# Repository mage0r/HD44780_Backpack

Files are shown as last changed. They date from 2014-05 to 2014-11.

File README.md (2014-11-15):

Attiny 84 LCD Display for the HD44780
=============

This project uses an Attiny 84 to drive LCD Displays that use the HD44780 driver.  It's simple, small and compatible with a range of sizes.  The board can easily be trimmed down to the standard 16x2 size or left at it's original size for 20x4.

This version includes a large prototyping area and a mounting for a "mesthingy" from http://www.m9design.co/

There are three sections, the circuit design for kicad, some i2c arduino sketches and a few photos of the finished product.

This version is compatible with Marc Merlin's NewLiquidCrystal library (https://github.com/marcmerlin)

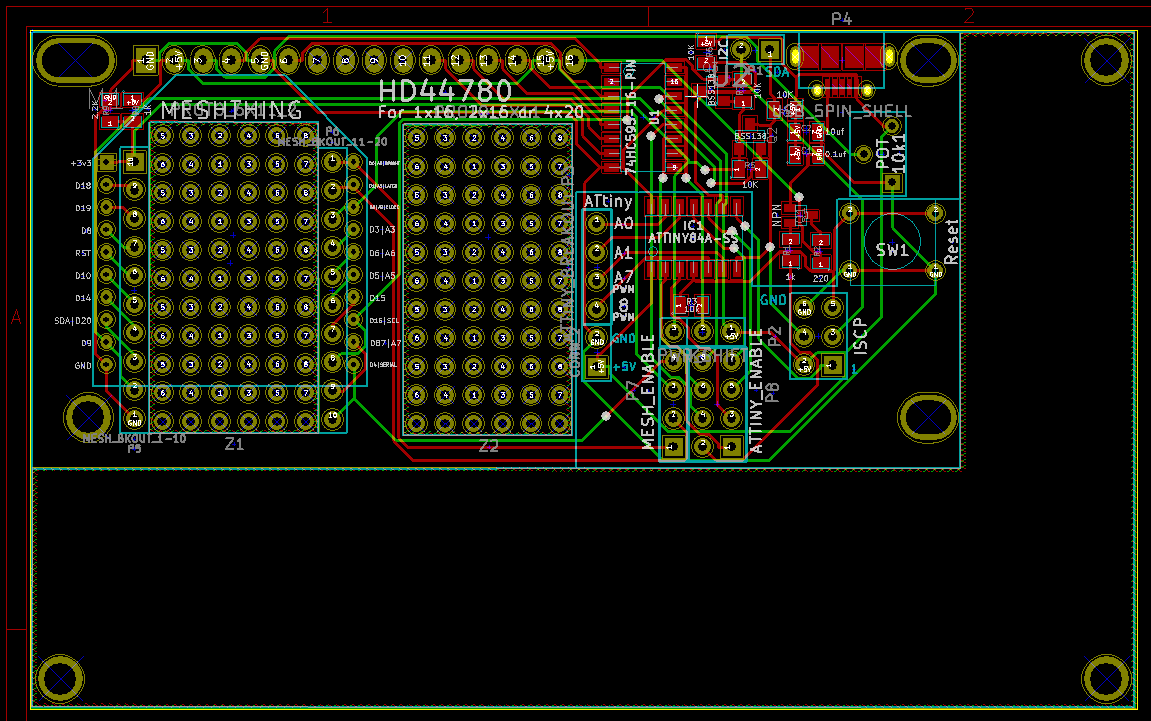
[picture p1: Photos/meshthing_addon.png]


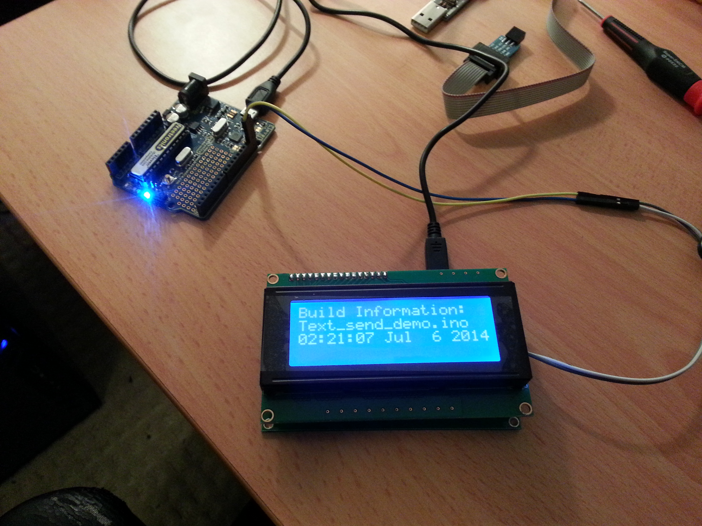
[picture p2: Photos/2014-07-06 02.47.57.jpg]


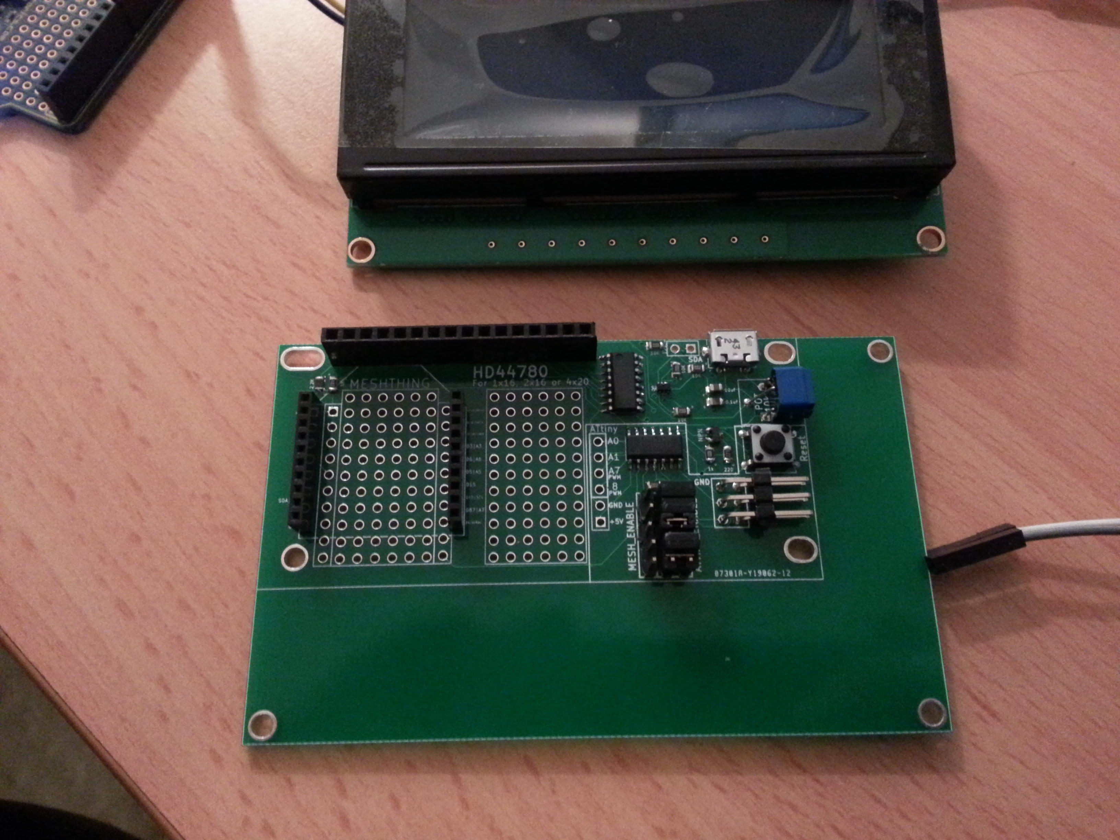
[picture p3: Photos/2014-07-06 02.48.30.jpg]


CREDITS
------------
This project was designed by John Spencer - john.spencer.9000@gmail.com - https://github.com/mage0r

SPECIAL THANKS
------------

To the HackMelbourne (CCHS, http://hackmelbourne.org) community of Melbourne, Australia.

To all other open-source developers whose countless hours supported every other aspect of this design.

DISTRIBUTION
------------
The specific terms of distribution of this project are governed by the
license referenced below. Please contact the copyright owner if you wish to modify the board for distribution. Please utilize this design for personal or research projects. Please acknowledge all contributors.

LICENSE
-------
Licensed under the TAPR Open Hardware License (www.tapr.org/OHL).
The "license" sub-folder also contains a copy of this license in plain text format.

Copyright John Spencer 2014
john.spencer.9000@gmail.com

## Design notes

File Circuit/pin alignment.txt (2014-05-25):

//   +--------------------------------------------+
//   |    attiny 84 		                  |
//   |    D03           D02           D09         |
//   +----+-------------+-------------+-----------+
//        |4            |5            |6
//        |1            |2            |3
//   +----+-------------+-------------+-----------+
//   |    Strobe        Data          Clock       |
//   |    74HC595 8-bit shift/latch register      |
//   |    QH   QG   QF   QE   QD   QC   QB   QA   |
//   +----+----+----+----+----+----+----+----+----+
//        |7   |6   |5   |4   |3   |2   |1   |15
//        |    |14  |13  |12  |11  |4   | 
//   +----+----+----+----+----+----+----+---------+
//   |         DB7  DB6  DB5  DB4  RS             |
//   |               LCD KS0066                   |
//   +--------------------------------------------

//   +----+-------------+-------------+-----------+
//   |    Strobe        Data          Clock       |
//   |          8-bit shift/latch register        | 74HC595N
//   |    Qa0  Qb1  Qc2  Qd3  Qe4  Qf5  Qg6  Qh7  |
//   +----+----+----+----+----+----+----+----+----+
//        |    |    |    |    |    |    |    
//        |11  |12  |13  |14  |6   |5   |4   (LCD pins)
//   +----+----+----+----+----+----+----+----+----+
//   |    DB4  DB5  DB6  DB7  E    Rw   RS        |
//   |                 LCD Module                 |
//
// NOTE: Rw is not used by the driver so it can be connected to GND

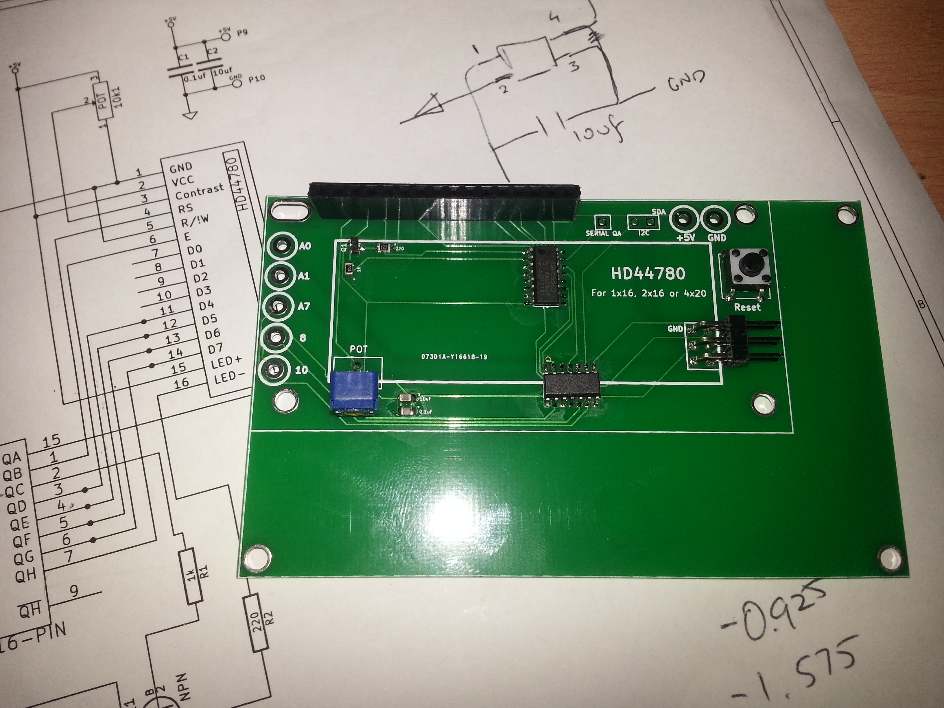
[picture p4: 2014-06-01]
Photos/2014-06-01 22.12.19.jpg

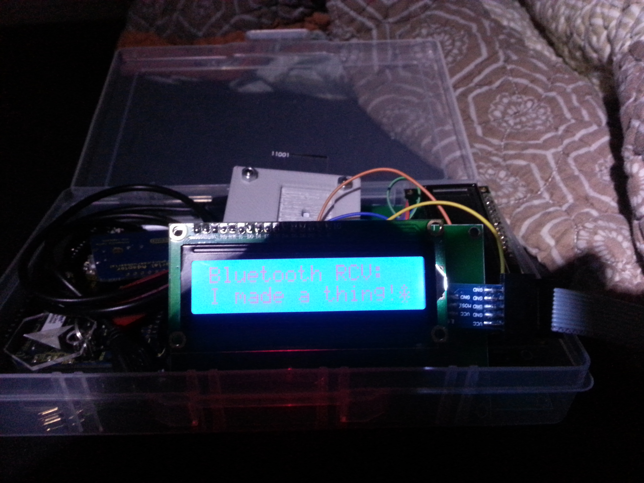
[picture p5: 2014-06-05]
Photos/2014-06-06 01.45.17.jpg

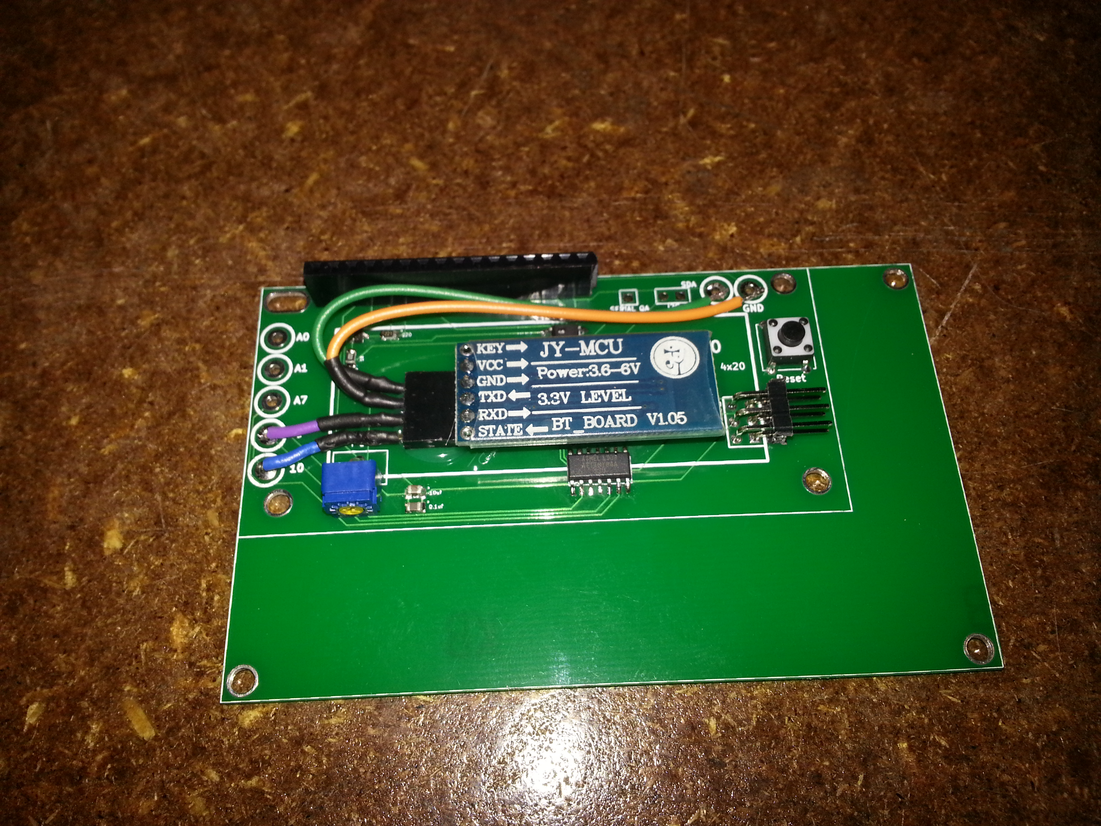
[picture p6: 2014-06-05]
Photos/2014-06-06 00.19.26.jpg

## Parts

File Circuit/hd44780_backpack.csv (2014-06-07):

ref | value | datasheet | footprint | Field1 | Field2 | Field3 | Field4 | Field5 | Field6 | Field7 | Field8
10k1 | POT | http://copal-electronics.info/en/00011/0064d.pdf | ~ | http://copal-electronics.info/en/00011/0064d.pdf | 0.77 | http://www.digikey.com.au/product-search/en?vendor=0&keywords=CT6EP103-ND
C1 | 0.1uf | ~ | ~ | ~
C2 | 10uf | ~ | ~ | ~
IC1 | ATTINY84A-SS | http://www.atmel.com/Images/doc8006.pdf | SO14 | http://www.atmel.com/Images/doc8006.pdf | 0.87
P1 | I2C | ~ | ~ | ~
P2 | ISCP | ~ | ~ | ~
P3 | A0
P4 | A1
P5 | A7
P6 | 8
P7 | 10
P8 | SERIAL QA
P9 | +5V
P10 | GND
Q1 | NPN | ~ | ~ | ~
R1 | 1k | ~ | ~ | ~
R2 | 220 | ~ | ~ | ~
SW1 | Reset | http://www.te.com/commerce/DocumentDelivery/DDEController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 | ~ | http://www.te.com/commerce/DocumentDelivery/DDEController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 | 0.1 | http://www.digikey.com.au/product-detail/en/FSM4JH/450-1650-ND/1632536
U1 | 74HC595-16-PIN | http://www.nxp.com/documents/data_sheet/74HC_HCT595.pdf | so-16 | http://www.nxp.com/documents/data_sheet/74HC_HCT595.pdf | 0.04
U2 | HD44780

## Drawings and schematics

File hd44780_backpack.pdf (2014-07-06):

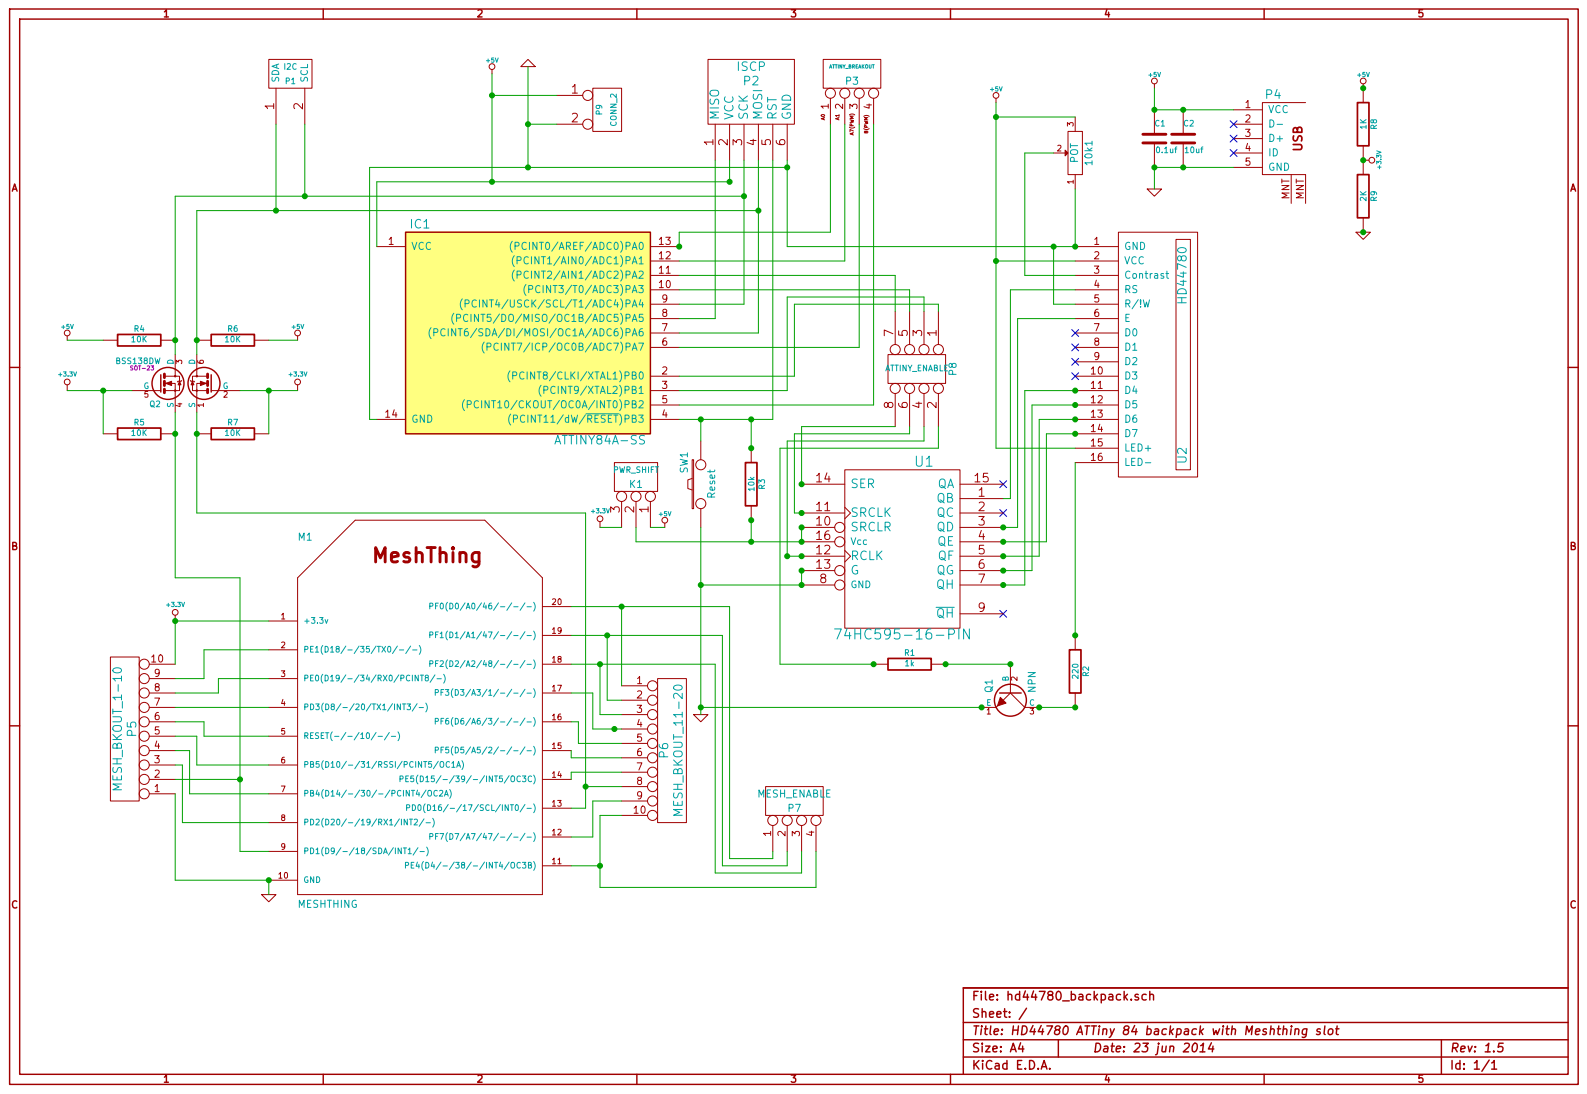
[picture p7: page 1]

File: hd44780_backpack.sch
Sheet: /
Title: HD44780 ATTiny 84 backpack with Meshthing slot
KiCad E.D.A.

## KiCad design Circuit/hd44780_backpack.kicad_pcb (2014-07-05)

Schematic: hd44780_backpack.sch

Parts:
10k1: POT
C1: 0.1uf
C2: 10uf
IC1: ATTINY84A-SS; SO14
K1: PWR_SHIFT
M1: MESHTHING; MeshThing
P1: I2C
P2: ISCP
P3: ATTINY_BREAKOUT
P4: USB_5PIN_SHELL
P5: MESH_BKOUT_1-10
P6: MESH_BKOUT_11-20
P7: MESH_ENABLE
P8: ATTINY_ENABLE
P9: CONN_2
Q1: NPN
Q2: BSS138DW; SOT-23
R1: 1k
R2: 220
R3: 10k
R4, R5, R6, R7: 10K
R8: 1K
R9: 2K
SW1: Reset
U1: 74HC595-16-PIN
U2: HD44780

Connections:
+3.3V: K1.3, M1.1 (+3.3v), P5.10, Q2.2 (G), Q2.5 (G), R5.1, R7.2, R8.2, R9.1
+5V: 10k1.3, C1.1, C2.1, IC1.1 (VCC), K1.1, P2.2 (VCC), P4.1 (VCC), P9.1, R4.1, R6.2, R8.1, U2.2 (VCC), U2.15 (LED+)
GND: 10k1.1, C1.2, C2.2, IC1.14 (GND), M1.10 (GND), P2.6 (GND), P4.5 (GND), P5.1, P9.2 (PM), Q1.1 (E), R9.2, SW1.1, U1.8, U1.13, U2.1 (GND), U2.5 (R/!W)
unnamed: U1.4, U2.14 (D7)
unnamed: IC1.11 ((PCINT2/AIN1/ADC2)PA2), P8.7
unnamed: R2.1, U2.16 (LED-)
unnamed: P8.2, R1.1
unnamed: Q1.3 (C), R2.2
unnamed: Q1.2 (B), R1.2
unnamed: U1.3, U2.6 (E)
unnamed: U1.1, U2.4 (RS)
unnamed: U1.5, U2.13 (D6)
unnamed: U1.6, U2.12 (D5)
unnamed: U1.7, U2.11 (D4)
unnamed: M1.15 (PF5(D5/A5/2/-/-/-)), P6.6
unnamed: M1.14 (PE5(D15/-/39/-/INT5/OC3C)), P6.7
unnamed: M1.11 (PE4(D4/-/38/-/INT4/OC3B)), P6.10, P7.4
unnamed: M1.12 (PF7(D7/A7/47/-/-/-)), P6.9
unnamed: P8.4, U1.12
unnamed: IC1.5 ((PCINT10/CKOUT/OC0A/INT0)PB2), P3.4 (8)
unnamed: IC1.6 ((PCINT7/ICP/OC0B/ADC7)PA7), P3.3 (A7)
unnamed: IC1.12 ((PCINT1/AIN0/ADC1)PA1), P3.2 (A1)
unnamed: IC1.8 ((PCINT5/DO/MISO/OC1B/ADC5)PA5), P2.1 (MISO)
unnamed: K1.2 (PM), R3.2, U1.10, U1.16
unnamed: IC1.13 ((PCINT0/AREF/ADC0)PA0), P3.1 (A0)
unnamed: IC1.4 ((PCINT11/dW/~RESET~)PB3), P2.5 (RST), R3.1, SW1.2
unnamed: 10k1.2, U2.3 (Contrast)
unnamed: P8.6, U1.11
unnamed: P8.8, U1.14
unnamed: IC1.2 ((PCINT8/CLKI/XTAL1)PB0), P8.1
unnamed: IC1.3 ((PCINT9/XTAL2)PB1), P8.3
unnamed: IC1.10 ((PCINT3/T0/ADC3)PA3), P8.5
unnamed: M1.19 (PF1(D1/A1/47/-/-/-)), P6.2, P7.2
unnamed: M1.20 (PF0(D0/A0/46/-/-/-)), P6.1, P7.1
unnamed: M1.18 (PF2(D2/A2/48/-/-/-)), P6.3, P7.3
unnamed: M1.16 (PF6(D6/A6/3/-/-/-)), P6.5
unnamed: M1.5 (RESET(-/-/10/-/-)), P5.6
unnamed: M1.17 (PF3(D3/A3/1/-/-/-)), P6.4
unnamed: M1.2 (PE1(D18/-/35/TX0/-/-)), P5.9
unnamed: M1.3 (PE0(D19/-/34/RX0/PCINT8/-)), P5.8
unnamed: M1.4 (PD3(D8/-/20/TX1/INT3/-)), P5.7
unnamed: M1.6 (PB5(D10/-/31/RSSI/PCINT5/OC1A)), P5.5
unnamed: M1.7 (PB4(D14/-/30/-/PCINT4/OC2A)), P5.4
unnamed: M1.8 (PD2(D20/-/19/RX1/INT2/-)), P5.3
unnamed: IC1.7 ((PCINT6/SDA/DI/MOSI/OC1A/ADC6)PA6), P1.1 (SDA), P2.4 (MOSI), Q2.6 (D), R6.1
unnamed: M1.13 (PD0(D16/-/17/SCL/INT0/-)), P6.8, Q2.1 (S), R7.1
unnamed: IC1.9 ((PCINT4/USCK/SCL/T1/ADC4)PA4), P1.2 (SCL), P2.3 (SCK), Q2.3 (D), R4.2
unnamed: M1.9 (PD1(D9/-/18/SDA/INT1/-)), P5.2, Q2.4 (S), R5.2

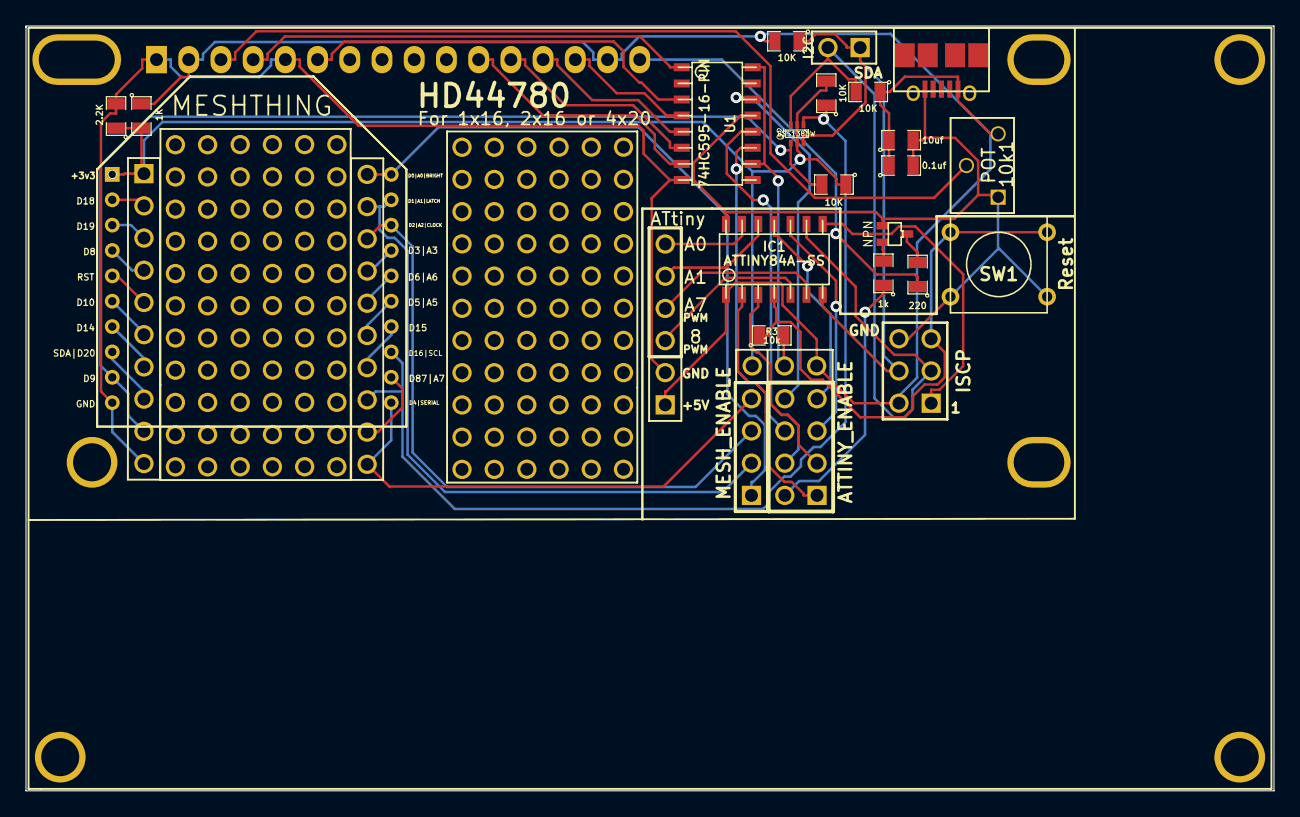
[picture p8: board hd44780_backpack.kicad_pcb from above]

Board: 2 copper layers, 98.4 x 60.3 mm, 31 parts (0 on the bottom side), 48 nets.

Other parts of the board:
PROTO_6X11: Z2; PROTO_6x11
PROTO_6X11_2: Z1; PROTO_6x11

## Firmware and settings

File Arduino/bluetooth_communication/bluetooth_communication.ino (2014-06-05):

/* This project combines the code from a few different sources.
This project was put together by ScottC on the 15/01/2013
http://arduinobasics.blogspot.com/

Bluetooth slave code by Steve Chang - downloaded from :
http://www.seeedstudio.com/wiki/index.php?title=Bluetooth_Shield

Changed for use on attiny 84 + Shift Register driven LCD panel by John Spencer, 2014

*/
 
#include <SoftwareSerial.h> //Software Serial Port
//#include <Wire.h>
#include <LiquidCrystal_SR_LCD3.h>

const int PIN_LCD_STROBE         =  9;  // Out: LCD IC4094 shift-register strobe
const int PIN_LCD_DATA           =  2;  // Out: LCD IC4094 shift-register data
const int PIN_LCD_CLOCK          =  3;  // Out: LCD IC4094 shift-register clock
const int PIN_LCD_BACKLIGHT      =  5;  // Out: LCD backlight (PWM)

// srdata / srclock / strobe
LiquidCrystal_SR_LCD3 lcd(PIN_LCD_DATA, PIN_LCD_CLOCK, PIN_LCD_STROBE);

#define RxD 8 // This is the pin that the Bluetooth (BT_TX) will transmit to the Arduino (RxD)
#define TxD 10 // This is the pin that the Bluetooth (BT_RX) will receive from the Arduino (TxD)
 
#define DEBUG_ENABLED 1

SoftwareSerial blueToothSerial(RxD,TxD);

String btName = "leostick";
String btPin = "1234";

String command = "";

/*----------------------SETUP----------------------------*/ 
void setup() { 
 //Serial.begin(9600); // Allow Serial communication via USB cable to computer (if required)
 
 pinMode(RxD, INPUT); // Setup the Arduino to receive INPUT from the bluetooth shield on Digital Pin 6
 pinMode(TxD, OUTPUT); // Setup the Arduino to send data (OUTPUT) to the bluetooth shield on Digital Pin 7
 
  
  lcd.begin(16, 2);
  
  //Serial.println("Waiting...");
  lcd.setCursor(0,0);
  lcd.print("I use Bluetooth...");
  lcd.setCursor(0,1);
  lcd.print("Connect to ");
  lcd.print(btName);
  
  setupBlueToothConnection(); //Used to initialise the Bluetooth shield

} 

/*----------------------LOOP----------------------------*/ 
void loop() { 
 char recvChar;

  if (blueToothSerial.available()) {
    while(blueToothSerial.available()) { // While there is more to be read, keep reading.
	command += (char)blueToothSerial.read();
    }
    //Serial.println(command);
    
    lcd.clear();
    lcd.setCursor(0,0);
    lcd.print("Bluetooth RCV:");
    
    lcd.setCursor(0,1);
    lcd.print(command);
    
    
     
    
    command = ""; // No repeats
  }
 
 /*
 //You can use the following code to deal with any information coming from the Computer (serial monitor)
 if(Serial.available()){
   recvChar = Serial.read();
   //This will send value obtained (recvChar) to the phone. The value will be displayed on the phone.
   blueToothSerial.print(recvChar);
   }
 */
} 



//The following code is necessary to setup the bluetooth shield ------copy and paste----------------
void setupBlueToothConnection()
{
 blueToothSerial.begin(9600); //Set BluetoothBee BaudRate to default baud rate 38400
 //blueToothSerial.print("\r\n+STWMOD=0\r\n"); //set the bluetooth work in slave mode
 //Serial.println("Sending name command to bluetooth\r\nAT+NAME = "+btName+"\r\n");
 //Serial.println(blueToothSerial.print("\r\nAT+NAME="+btName+"\r\n")); //set the bluetooth name
 //blueToothSerial.print("\r\n+STOAUT=1\r\n"); // Permit Paired device to connect me
 //blueToothSerial.print("\r\n+STAUTO=0\r\n"); // Auto-connection should be forbidden here
 delay(2000); // This delay is required.
 //blueToothSerial.print("\r\n+INQ=1\r\n"); //make the slave bluetooth inquirable 
 //Serial.println("The slave bluetooth is inquirable!");
 delay(2000); // This delay is required.
 blueToothSerial.flush();
}

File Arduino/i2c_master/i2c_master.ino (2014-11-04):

/*

  Control menu for I2C HD44780 backpacks.
  John Spencer - 2014
  https://github.com/mage0r/HD44780_Backpack
  
  Adapted from:
  http://www.forkrobotics.com/2012/05/relay-control-over-i2c/
  
  
  
*/

#include <Wire.h>
byte ATtinyAddress; // this is the address we are sending to.  Set in setup()

String inputString = "";         // a string to hold incoming data
boolean stringComplete = false;  // whether the string is complete

String receiveString = "";

int toReceive = 0;

void setup(){
    Wire.begin();
    Serial.begin(9600);
    
    inputString.reserve(200);
    findDevices(); // who is on this bus?
    PrintMenu();
    Serial.print("Writing to device: ");
    Serial.println(ATtinyAddress);
    
}
void loop(){
  
  // check if we're recieving any data we've requested.
  while(Wire.available())    // slave may send less than requested
  { 
    if(toReceive < 0) {
      int test_wire = (int)Wire.read();
      if(test_wire > 0) {
        toReceive = test_wire;
        //Serial.println(toReceive);
      }
    } 
    else {
      char c = Wire.read(); // receive a byte as character
      //Serial.print(c);         // print the character
      receiveString += c;
      
      toReceive--;
    }
    
    if (toReceive > 0) {// still more data to get
      Wire.requestFrom((int)ATtinyAddress, 1);
    } else if (toReceive < 0) { 
      // we're still expecting a value
      // got a little delay thing happening here.
      // Serial.print("."); // unfortunately this gives a kind of messy output.
      delay(100);
      toReceive --;
      if ( toReceive > -10 )
        Wire.requestFrom((int)ATtinyAddress, 1);
       else
         Serial.println("Receive Timeout"); 
    } 
    //else
    //  Serial.println();

  }
  
  if (receiveString.length() == 8) {
    Serial.println(debinaryStringify(receiveString));
    receiveString = "";
  } else if (receiveString.length() > 0) {
    Serial.println(receiveString);
    receiveString = "";
  }

  
  char inSerial; // temporary serial character
  
  if(Serial.available()){
     inSerial = (char)Serial.read();
     
       inputString += inSerial;
     
     if (inSerial == ';')
       stringComplete = true;
   }
   
   // finished getting the string from the terminal.  what are we trying to do?
   if (stringComplete) {
     
     CheckCommands();
     
     inputString = "";
     stringComplete = false;
   }

}

String debinaryStringify(String source) {
    String result = "";
    int idxStart = 0;
    do {
        char val = 0;
        for (int i=0; i<8; i++) {
            val += ((source.charAt(idxStart+i) == '1') << (7-i)); // Trick: Assignment of an evaluation result
        }
        result.concat(val);
        idxStart = source.indexOf(' ') + 1;
    } while ( (idxStart > 0) && (idxStart < source.length() - 7) );
    return result;
}

boolean CheckCommands() {
  if ( inputString.charAt(0) == 'A' ) {
       ATtinyAddress = inputString.substring(2,inputString.length()-1).toInt();
       Serial.print("Writing to device: ");
       Serial.println(ATtinyAddress);
     }
     else if ( inputString.charAt(0) == '?' && inputString.charAt(2) != '?') {
       PrintBuild();
       PrintMenu();
     }
     else if ( inputString.charAt(0) == 'F' ) {
       findDevices();
     }
     else if ( inputString.charAt(1) == ':' ) { // we're sending something out, doesn't matter what.
       toReceive = -1;
       SendI2C(ATtinyAddress,inputString);
       Wire.requestFrom((int)ATtinyAddress, 1); // just ask for our count character.
     }
     else
     {
       Serial.print("Sending:");
       Serial.println(inputString);
       SendI2C(ATtinyAddress,inputString);
     }
}

void PrintMenu(){
  Serial.println("--- Relay Menu ---");
  Serial.println("F; // Scan for Devices");
  Serial.println("?; // Show build information and this menu");
  Serial.println("A:38; // set i2c write address to 38");
  Serial.println("------Screen Remote Commands---------");
  Serial.println("R:39; // set remote i2c write address of current to 39");
  Serial.println("C:; // clear the screen");
  Serial.println("S:; // Show the screen");
  Serial.println("H:; // Hide the screen");
  Serial.println("B:100; // Change the backlight value ");
  Serial.println("M:0,1,2,3; // Put custom character '0' at row '1', column '2' ");
  Serial.println("?:?; // Build information");
}

void PrintBuild(){
  Serial.println("Build Information:");
  Serial.println(__FILE__);
  Serial.print(__TIME__);
  Serial.print("  ");
  Serial.println(__DATE__);
}

void SendI2C(int device,String data) {
  
  char buffer[32];
  data.toCharArray(buffer,32);
  Wire.beginTransmission(device);
  Wire.write(buffer);
  Wire.endTransmission();
}

void findDevices()
{
  byte error, address;
  
  // reset our write address to zero before we start
  // Just know I will regret this...
  ATtinyAddress = 0;

  Serial.println("Scanning for i2c devices...");

  for(address = 1; address < 127; address++ ) 
  {
    // The i2c_scanner uses the return value of
    // the Write.endTransmisstion to see if
    // a device did acknowledge to the address.
    Wire.beginTransmission(address);
    error = Wire.endTransmission();

    if (error == 0)
    {
      Serial.print("I2C device found at address: ");
      Serial.print(address);
      Serial.println("  !");
      
      if(!ATtinyAddress) // if we're blank, set the first address we find as the send.
        ATtinyAddress = address;
    }
  }
  Serial.println("Done Scanning.");
}

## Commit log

2014-05-25 initial commit
    I've already lost hardware changes once already...
    [hd44780_backpack.dsn, hd44780_backpack.sch]
2014-05-25 not sure why this wasn't included before
    [hd44780_backpack.kicad_pcb]
2014-06-01 Modified Library
    Modified library included to handle a different pin output on the Shift
    Register than the default library expects.
2014-06-01 Example sketch replaced
    The replacement sketch now has the correct arduino pin-outs and the
    other non-relevant examples have been removed.
2014-06-01 Added github link to text on back of board
    [hd44780_backpack.kicad_pcb]
2014-06-02 non-working circuit.
    [hd44780_backpack.dsn, hd44780_backpack.kicad_pcb, hd44780_backpack.sch]
2014-06-02 Meshthing integration complete
    [hd44780_backpack.dsn, hd44780_backpack.kicad_pcb, hd44780_backpack.sch]
2014-06-02 missed a few files
    [hd44780_backpack.kicad_pcb]
2014-06-04 Changed to using a BSS138DW
    [hd44780_backpack.dsn, hd44780_backpack.kicad_pcb, hd44780_backpack.sch]
2014-06-07 Added links to components
    and prices to build a bom.
    [hd44780_backpack.csv, hd44780_backpack.sch]
2014-06-23 problem with back masks
    the meshthingy had no back mask area. made it very difficult to solder.
    [hd44780_backpack.kicad_pcb, hd44780_backpack.sch]
2014-07-02 test i2c code.
    Simple send text
2014-07-05 working i2c master and slave
    Can now do a bunch of operations using the i2c bus
2014-07-06 Added Schematic pdf
    For easy viewing.
    [hd44780_backpack.sch]
2014-11-04 improvements to i2c communications
